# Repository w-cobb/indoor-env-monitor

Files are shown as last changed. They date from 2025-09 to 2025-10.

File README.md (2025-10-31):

# Indoor Environment monitor

## Description
This is a project I created to monitor the conditions of my living space. The main inspiration behind this project was to monitor indoor air quality in order to know when
to turn on air purifiers. Since I live in an area that can have poor air quality during the summer months, it could be useful to have localized data for this purpose.

## Specifications
This project was created in VS Code with the ESP IDF v5.5 extension. The hardware used is listed in the table below.

| Component | Description |
| :---: | :---: |
| ESP32 | ESP32 C6-Mini-1 |
| BME280 | Adafruit BME280 STEMMA QT board |
| PMS5003 | Adafruit PM2.5 Air Quality Sensor and Breadboard Adapter Kit |

## State of the Project
Everything below this will act as a development blog.

## October 30, 2025
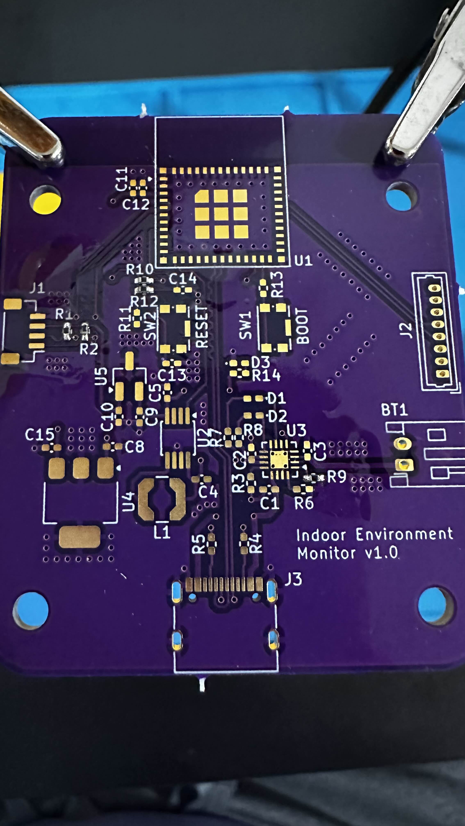
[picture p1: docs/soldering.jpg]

Soldering has begun.

Disclaimer: I am not an electrical engineer and have no formal training in hardware/pcb design. I understand now that some of my passive component choices might not be ideal. In any case, I don't think I will be using 0402 size components unless absolutely necessary. They are TINY! :D

## October 24, 2025
All components have arrived, except for that one silly cable for the BME280 board that I forgot to order from Adafruit.

## October 11, 2025
PCB design is done (for now) and I have ordered the PCBs from OSHPark.

## September 23, 2025
I want to move this project off the breadboard into a more compact design. I decided to start designing a PCB in KiCad.

## September 19, 2025
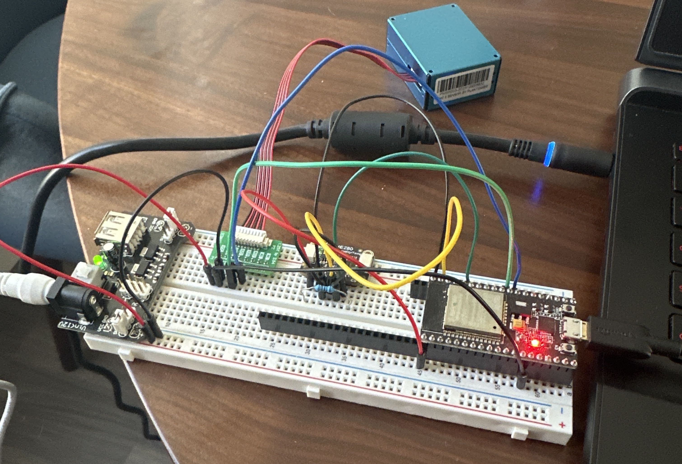
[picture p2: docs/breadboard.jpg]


Breadboarding is complete. Data is being read from both sensors as seen below.

output

## September 15, 2025
The BME280 is currently communicating over I2C using a custom driver and the ESP IDF HAL.

The next step is to write a custom driver for the PMS5003 sensor utilizing UART.

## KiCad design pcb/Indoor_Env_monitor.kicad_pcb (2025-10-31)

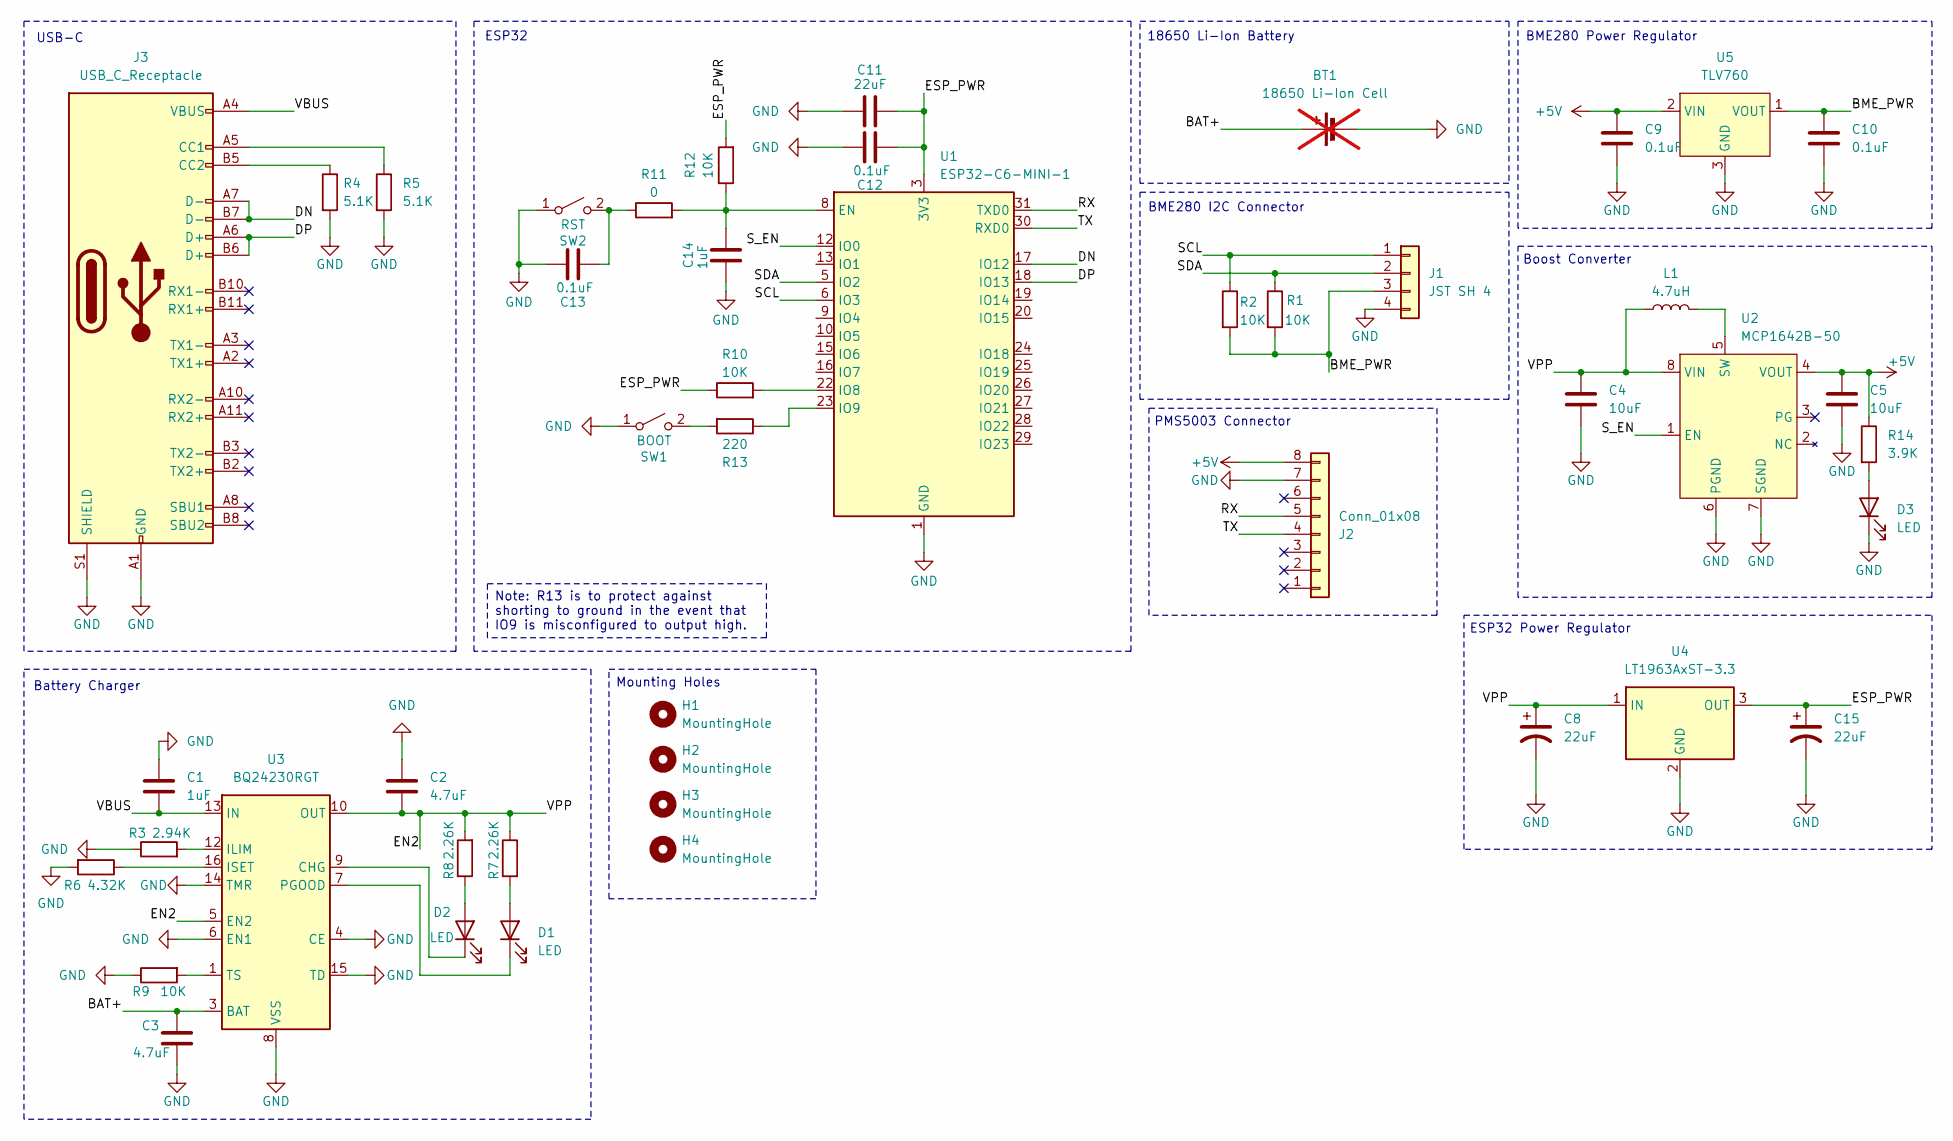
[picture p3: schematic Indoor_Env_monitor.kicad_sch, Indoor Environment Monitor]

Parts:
BT1: 18650 Li-Ion Cell; JST_PH_S2B-PH-K_1x02_P2.00mm_Horizontal; not fitted
C1, C14: 1uF; C_0402_1005Metric_Pad0.74x0.62mm_HandSolder
C2, C3: 4.7uF; C_0402_1005Metric_Pad0.74x0.62mm_HandSolder
C4, C5: 10uF; C_0402_1005Metric_Pad0.74x0.62mm_HandSolder
C8, C11, C15: 22uF; C_0402_1005Metric_Pad0.74x0.62mm_HandSolder
C9, C10, C12, C13: 0.1uF; C_0402_1005Metric_Pad0.74x0.62mm_HandSolder
D1, D2, D3: LED; LED_0402_1005Metric_Pad0.77x0.64mm_HandSolder
H1, H2, H3, H4: MountingHole; MountingHole_3.2mm_M3
J1: JST SH 4; JST_SH_BM04B-SRSS-TB_1x04-1MP_P1.00mm_Vertical
J2: Conn_01x08; Molex_PicoBlade_53047-0810_1x08_P1.25mm_Vertical
J3: USB_C_Receptacle; USB_C_Receptacle_G-Switch_GT-USB-7010ASV
L1: 4.7uH; L_Coilcraft_LPS4018
R1, R2, R9, R10, R12: 10K; R_0402_1005Metric_Pad0.72x0.64mm_HandSolder
R3: 2.94K; R_0402_1005Metric_Pad0.72x0.64mm_HandSolder
R4, R5: 5.1K; R_0402_1005Metric_Pad0.72x0.64mm_HandSolder
R6: 4.32K; R_0402_1005Metric_Pad0.72x0.64mm_HandSolder
R7, R8: 2.26K; R_0402_1005Metric_Pad0.72x0.64mm_HandSolder
R11: 0; R_0402_1005Metric_Pad0.72x0.64mm_HandSolder
R13: 220; R_0402_1005Metric_Pad0.72x0.64mm_HandSolder
R14: 3.9K; R_0402_1005Metric_Pad0.72x0.64mm_HandSolder
SW1: BOOT; SW_Push_1P1T-SH_NO_CK_KMR2xxG
SW2: RST; SW_Push_1P1T-SH_NO_CK_KMR2xxG
U1: ESP32-C6-MINI-1
U2: MCP1642B-50; MSOP-8_3x3mm_P0.65mm
U3: BQ24230RGT; VQFN-16-1EP_3x3mm_P0.5mm_EP1.68x1.68mm_ThermalVias
U4: LT1963AxST-3.3; SOT-223-3_TabPin2
U5: TLV760; SOT-23_Handsoldering

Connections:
+5V: C5.1, C9.1, J2.8, R14.1, U2.4 (VOUT), U5.2 (VIN)
/BAT+: BT1.1 (+), C3.1, U3.2 (BAT), U3.3 (BAT)
/BME_PWR: C10.1, J1.3, R1.2, R2.2, U5.1 (VOUT)
/DN: J3.A7 (D-), J3.B7 (D-), U1.17 (IO12)
/DP: J3.A6 (D+), J3.B6 (D+), U1.18 (IO13)
/EN2: C2.2, C4.1, C8.1, L1.1, R7.1, R8.2, U2.8 (VIN), U3.5 (EN2), U3.10 (OUT), U3.11 (OUT), U4.1 (IN)
/ESP_PWR: C11.2, C12.2, C15.1, R10.1, R12.2, U1.3 (3V3), U4.3 (OUT)
/RX: J2.5, U1.31 (TXD0)
/SCL: J1.1, R2.1, U1.6 (IO3)
/SDA: J1.2, R1.1, U1.5 (IO2)
/S_EN: U1.12 (IO0), U2.1 (EN)
/TX: J2.4, U1.30 (RXD0)
/VBUS: C1.2, J3.A4 (VBUS), J3.A9 (VBUS), J3.B4 (VBUS), J3.B9 (VBUS), U3.13 (IN)
GND: BT1.2 (-), C1.1, C2.1, C3.2, C4.2, C5.2, C8.2, C9.2, C10.2, C11.1, C12.1, C13.1, C14.2, C15.2, D3.1 (K), J1.4, J2.7, J3.A1 (GND), J3.A12 (GND), J3.B1 (GND), J3.B12 (GND), J3.S1 (SHIELD), R3.1, R4.2, R5.2, R6.2, R9.1, SW1.1 (A), SW2.1 (A), U1.1 (GND), U1.2 (GND), U1.11 (GND), U1.14 (GND), U1.36 (GND), U1.37 (GND), U1.38 (GND), U1.39 (GND), U1.40 (GND), U1.41 (GND), U1.42 (GND), U1.43 (GND), U1.44 (GND), U1.45 (GND), U1.46 (GND), U1.47 (GND), U1.48 (GND), U1.49 (GND), U1.50 (GND), U1.51 (GND), U1.52 (GND), U1.53 (GND), U2.6 (PGND), U2.7 (SGND), U3.4 (CE), U3.6 (EN1), U3.8 (VSS), U3.14 (TMR), U3.15 (TD), U3.17 (VSS), U4.2 (GND), U5.3 (GND)
unnamed: D1.2 (A), R7.2
unnamed: D1.1 (K), U3.7 (PGOOD)
unnamed: D2.2 (A), R8.1
unnamed: D2.1 (K), U3.9 (CHG)
unnamed: D3.2 (A), R14.2
unnamed: J3.A5 (CC1), R5.1
unnamed: J3.B5 (CC2), R4.1
unnamed: R13.2, SW1.2 (B)
unnamed: C13.2, R11.1, SW2.2 (B)
unnamed: C14.1, R11.2, R12.1, U1.8 (EN)
unnamed: R10.2, U1.22 (IO8)
unnamed: R13.1, U1.23 (IO9)
unnamed: L1.2, U2.5 (SW)
unnamed: R3.2, U3.12 (ILIM)
unnamed: R6.1, U3.16 (ISET)
unnamed: R9.2, U3.1 (TS)

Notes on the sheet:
BME280 I2C Connector
Mounting Holes
PMS5003 Connector
ESP32
BME280 Power Regulator
18650 Li-Ion Battery
Battery Charger
Boost Converter
ESP32 Power Regulator
USB-C
Note: R13 is to protect against shorting to ground in the event that IO9 is misconfigured to output high.

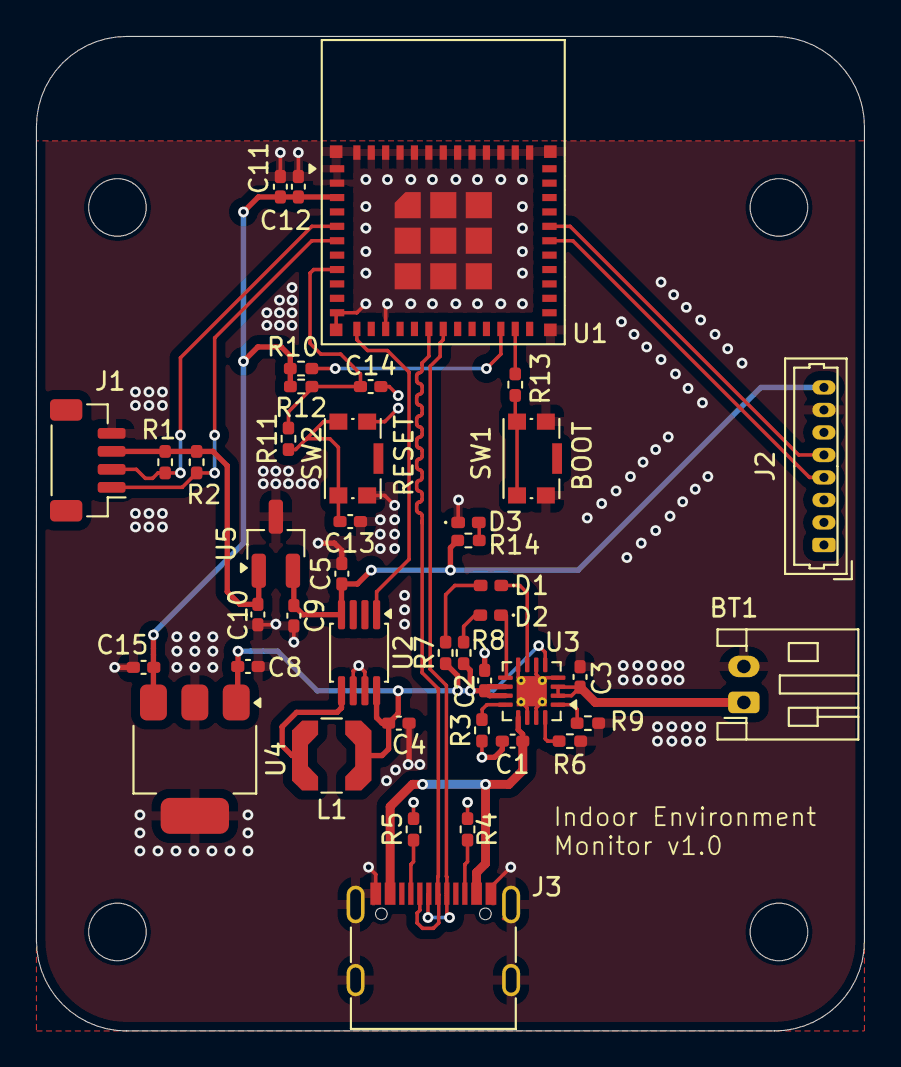
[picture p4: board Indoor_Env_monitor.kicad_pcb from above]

Board: 2 copper layers, 46.0 x 55.2 mm, 46 parts (0 on the bottom side), 30 nets.

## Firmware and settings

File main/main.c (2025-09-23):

#include <stdio.h>
#include "sdkconfig.h"
#include "freertos/FreeRTOS.h"
#include "freertos/task.h"
#include "driver/i2c_master.h"
#include "driver/i2c.h"
#include "../components/bme280/bme280.h"
#include "../components/pms5003/pms5003.h"

#define I2C_MASTER_SCL_IO           CONFIG_I2C_MASTER_SCL
#define I2C_MASTER_SDA_IO           CONFIG_I2C_MASTER_SDA
#define I2C_MASTER_NUM              I2C_NUM_0
#define I2C_MASTER_FREQ_HZ          CONFIG_I2C_MASTER_FREQUENCY
#define I2C_MASTER_TX_BUF_DISABLE   0
#define I2C_MASTER_RX_BUF_DISABLE   0
#define I2C_MASTER_TIMEOUT_MS       1000


void initI2cBus(i2c_master_bus_handle_t *bus_handle) {
    i2c_master_bus_config_t bus_config = {
        .i2c_port = I2C_MASTER_NUM,
        .sda_io_num = (gpio_num_t)I2C_MASTER_SDA_IO,
        .scl_io_num = (gpio_num_t)I2C_MASTER_SCL_IO,
        .clk_source = I2C_CLK_SRC_DEFAULT,
        .glitch_ignore_cnt = 7,
        .flags = {.enable_internal_pullup = true}
    };
    ESP_ERROR_CHECK(i2c_new_master_bus(&bus_config, bus_handle));
}

void addI2cDevice(i2c_master_bus_handle_t *bus_handle, i2c_master_dev_handle_t *dev_handle) {
    i2c_device_config_t dev_config = {
        .dev_addr_length = I2C_ADDR_BIT_LEN_7,
        .device_address = BME280_I2C_ADDR,
        .scl_speed_hz = I2C_MASTER_FREQ_HZ,
    };
    ESP_ERROR_CHECK(i2c_master_bus_add_device(*bus_handle, &dev_config, dev_handle));
}

void app_main(void)
{
    i2c_master_bus_handle_t bus_handle;
    i2c_master_dev_handle_t bme280_handle;
    printf("Initializing I2C...\n");
    initI2cBus(&bus_handle);
    addI2cDevice(&bus_handle, &bme280_handle);
    printf("Done initializing.\n");

    bme280_init(&bme280_handle);
    pms5003_init();

    while (1) {
        printf("Reading data...\n");
        bme280_read_data();
        pms5003_read_data();
        printf("Done reading data.\n");
        printf("Temperature: %.2fC, Humidity: %.2fRH, Pressure: %.2fPa\n",
            bme280data.temp, bme280data.hum, bme280data.press);
        printf("PM1.0 Concentration: %u ug/m^3, 1.0 um Particle Count: %u\n", 
            pms5003Data.pm1_0_conc_atmos, pms5003Data.particles_1_0);
        printf("PM2.5 Concentration: %u ug/m^3, 2.5 um Particle Count: %u\n", 
            pms5003Data.pm2_5_conc_atmos, pms5003Data.particles_2_5);
        printf("PM10.0 Concentration: %u ug/m^3, 10.0 um Particle Count: %u\n", 
            pms5003Data.pm10_conc_atmos, pms5003Data.particles_10);
        
        vTaskDelay(5000 / portTICK_PERIOD_MS);
    }
}

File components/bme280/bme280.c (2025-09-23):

#include "bme280.h"
#include "freertos/FreeRTOS.h"
#include "freertos/task.h"
#include <portmacro.h>

// Static function declarations

static void readCalibData();
static uint8_t readRegister8(uint8_t reg);
static uint16_t readRegister16(uint8_t reg);
static void burstReadData(uint8_t *buffer);
static void writeRegister(uint8_t reg, uint8_t data);
static void writeConfig();
static float compensateT(BME280_S32_t adc_T);
static float compensateH(BME280_S32_t adc_H);
static float compensateP(BME280_S32_t adc_P);

bme280_data bme280data;
bme280_config config;

i2c_master_dev_handle_t _dev_handle;
bme280_calib_data _calib;

BME280_S32_t _t_fine;

/*
Initialize the sensor with the device handle for I2C communication, read the callibration registers,
and perform inital configuration of the sensor.
*/
void bme280_init(i2c_master_dev_handle_t *dev_handle) {
    printf("Assigning handle\n");
    _dev_handle = *dev_handle;

    // Wait for power-on-reset to complete
    printf("Waiting for power-on-resset to finish...\n");
    while (readRegister8(BME280_REG_ID) != 0x60);
    printf("Fetched the sensor ID.\n");

    printf("Reading calibration registers\n");
    readCalibData();
    printf("Done\n");

    printf("Writing to config registers\n");
    writeConfig();
    printf("Config written\n");

    // Configure
    config.id = 0x60;
    config.osrs_h = sample_x1;
    config.osrs_t = sample_x1;
    config.osrs_p = sample_x1;
    config.mode = sleep;
    config.t_sb = sb1000;
    config.filter = filter_off;
    config.spi32_en = 0;
    
    bme280data.temp = 0.0f;
    bme280data.press = 0.0f;
    bme280data.hum = 0.0f;
}

/*
Read data into the data struct.
*/
void bme280_read_data() {
    // Set sensor mode to forced and wait for data to be available.
    printf("Entering forced mode\n");
    config.mode = forced;
    writeConfig();
    printf("Forced mode on\n");
    while ((readRegister8(BME280_REG_STATUS) & 0x8) == 0x8);
    printf("Data is now available\n");

    // Burst read the data registers
    uint8_t buffer[8];
    burstReadData(buffer);

    printf("Data registers have been read\n");
    // Run the compensation formulas on the data values
    BME280_S32_t adc_P, adc_T, adc_H;

    // Read adc values from buffer
    adc_P = buffer[0] << 12 | buffer[1] << 4 | (buffer[2] & 0xF);
    adc_T = buffer[3] << 12 | buffer[4] << 4 | (buffer[5] & 0xF);
    adc_H = buffer[6] << 8 | buffer[7];


    // Convert adc values to float and store them in data struct.
    bme280data.temp = compensateT(adc_T) / 100.0f;
    bme280data.press = compensateP(adc_P) / 256 / 100.0f;
    bme280data.hum = compensateH(adc_H) / 1024.0f;
}

/*
Read the calibration registers into the _calib struct.
*/
static void readCalibData() {
    // Read calibration data registers
    _calib.dig_T1 = readRegister16(BME280_CALIB_DIG_T1);
    _calib.dig_T2 = (int16_t)readRegister16(BME280_CALIB_DIG_T2);
    _calib.dig_T3 = (int16_t)readRegister16(BME280_CALIB_DIG_T3);
    _calib.dig_P1 = readRegister16(BME280_CALIB_DIG_P1);
    _calib.dig_P2 = (int16_t)readRegister16(BME280_CALIB_DIG_P2);
    _calib.dig_P3 = (int16_t)readRegister16(BME280_CALIB_DIG_P3);
    _calib.dig_P4 = (int16_t)readRegister16(BME280_CALIB_DIG_P4);
    _calib.dig_P5 = (int16_t)readRegister16(BME280_CALIB_DIG_P5);
    _calib.dig_P6 = (int16_t)readRegister16(BME280_CALIB_DIG_P6);
    _calib.dig_P7 = (int16_t)readRegister16(BME280_CALIB_DIG_P7);
    _calib.dig_P8 = (int16_t)readRegister16(BME280_CALIB_DIG_P8);
    _calib.dig_P9 = (int16_t)readRegister16(BME280_CALIB_DIG_P9);
    _calib.dig_H1 = readRegister8(BME280_CALIB_DIG_H1);
    _calib.dig_H2 = (int16_t)readRegister16(BME280_CALIB_DIG_H2);
    _calib.dig_H3 = readRegister8(BME280_CALIB_DIG_H3);
    _calib.dig_H4 = (int16_t)(readRegister8(BME280_CALIB_DIG_H4) << 4 | (readRegister8(BME280_CALIB_DIG_H5) & 0xF));
    _calib.dig_H5 = (int16_t)(readRegister8(0xE6) << 4 | (readRegister8(BME280_CALIB_DIG_H5) & 0xF));
    _calib.dig_H6 = (int8_t)readRegister8(BME280_CALIB_DIG_H6);
}

/**
Write changes to configuration registers. Configuration is stored in the "config" struct.
*/
static void writeConfig() {
    // Write configuration
    writeRegister(BME280_REG_CTRLHUM, config.osrs_h);
    uint8_t temp = config.osrs_t << 5 | config.osrs_p << 2 | config.mode; // ctrl_meas
    writeRegister(BME280_REG_CTRLMEAS, temp);
    temp = config.t_sb << 5 | config.filter << 2 | config.spi32_en; // config
    writeRegister(BME280_REG_CONFIG, temp);
}

/*
Read an unsigned char from given register address.
*/
static uint8_t readRegister8(uint8_t reg) {
    uint8_t temp;
    i2c_master_transmit_receive(_dev_handle, &reg, 1, &temp, 1, 1000 / portTICK_PERIOD_MS);
    return temp;
}

/*
Read an unsigned short from given register address.
*/
static uint16_t readRegister16(uint8_t reg) {
    uint8_t temp[2];
    i2c_master_transmit_receive(_dev_handle, &reg, 1, temp, 2, 1000 / portTICK_PERIOD_MS);
    return (uint16_t)(temp[1] << 8 | temp[0]);
}

/*
Read from all data registers at once (burst read). This is recommended to prevent inconsistent data read between measurement cycles.
*/
static void burstReadData(uint8_t *buffer) {
    // Read from all data registers at once
    printf("Reading data registers...\n");
    uint8_t reg = BME280_REG_PRESS;
    ESP_ERROR_CHECK(i2c_master_transmit(_dev_handle, &reg, 1, -1));
    ESP_ERROR_CHECK(i2c_master_receive(_dev_handle, buffer, 8, -1));
    printf("Done\n");
}

/*
Write an unsigned char to register at the given address. This is performed by sending pairs of register addresses and data. i.e. write [reg, data]
*/
static void writeRegister(uint8_t reg, uint8_t data) {
    uint8_t buffer[2] = {reg, data};
    i2c_master_transmit(_dev_handle, buffer, 2, 1000 / portTICK_PERIOD_MS);
}

/*
Convert adc temperature value to float using the formula given in section 4.2.3 of the BME280 datasheet.
*/
static float compensateT(BME280_S32_t adc_T) {
    BME280_S32_t var1, var2, T;
    var1 = ((((adc_T >> 3) - ((BME280_S32_t)_calib.dig_T1 << 1))) * ((BME280_S32_t)_calib.dig_T2)) >> 11;
    var2 = (((((adc_T >> 4) - ((BME280_S32_t)_calib.dig_T1)) * ((adc_T >> 4) - ((BME280_S32_t)_calib.dig_T1))) >> 12) *
            ((BME280_S32_t)_calib.dig_T3)) >> 14;
    _t_fine = var1 + var2;
    T = (_t_fine * 5 + 128) >> 8;
    return (float)T;
}
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

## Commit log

2025-09-16 Reverted code back to C
    [bme280.c, main.c]
2025-09-16 Fixed writeConfig overwriting config every loop
    [bme280.c]
2025-09-23 Add code to read data over UART from PMS5003 sensor
2025-09-23 Add configuration attributes for configuring UART
2025-09-23 Read and print data from PMS5003
2025-09-23 Added pcb folder, KiCad files, and entry to gitignore for KiCad backups
    [Indoor_Env_monitor.kicad_pcb, Indoor_Env_monitor.kicad_sch]
2025-10-14 Created the schematic and PCB
    [Indoor_Env_monitor.kicad_pcb, Indoor_Env_monitor.kicad_sch]
2025-10-18 Little change
    [Indoor_Env_monitor.kicad_sch]
